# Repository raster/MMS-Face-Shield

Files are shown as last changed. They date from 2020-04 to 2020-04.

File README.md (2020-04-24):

# MMS Face Shield

This is a face shield being produced by [Milwaukee Makerspace](https://milwaukeemakerspace.org/) in Milwaukee, Wisconsin, USA.

Our design is based on v3 of the 3DVerkstan design, North American 6 hole version:

 * https://3dverkstan.se/protective-visor/protective-visor-versions/
 * https://www.youmagine.com/designs/protective-visor-by-3dverkstan/
 * https://github.com/Cederb/Faceshield.nu/

We have modified the frame to be cut from 1/4" HDPE on a CNC router. HDPE (High-density Polyethylene) is often used for cutting boards and high-touch surfaces.

_(Note: As of 2020-04-20 we have switched to using injection molding. More info below.)_

The shield will be stamped from 0.01" thick rigid clear vinyl. (We originally planned to cut with a drag knife on our CNC machine but we have found local companies that have offered to create a die and stamp them for us.)

Because of our material choices it will be easy to clean & sanitize these face shields. We're also facing a shortage of PETG sheets, so using clear vinyl that was available to us was a good option.

## Frame (CNC)

The frame is cut from 1/4" HDPE sheets on a CNC router using a 1/8" single flute spiral upcut endmill. (Note: HDPE cannot be cut on a laser cutter, but it is a great material for milling.)

## Frame (Injection Molded)

We have added the STEP file (Frame-Injection-Molding-v7.step) as we have moved to an injection molded version of the frame. This version may help if you are looking at doing injection molding. We are using HDPE plastic for our injection molded frames. We can easily produce 2000+ frames per day and the mold should be able to produce 200,000 frames during its lifetime.

We've also included an STL file (Frame-Injection-Molding-v7.stl) _for reference only!_ We make no guarantees as to the accuracy of the STL file for use beyond anything more than as a test print.

## Shield

The shield files are 8 1/2" x 11". If you can source letter size plastic you can find a variety of options for adding the holes. (The rounded corners at the bottom are not required, but are nice to have as they help prevent snagging the corner of the shield on something.)

## Cleaning

Please see the included PDF file with instructions for cleaning this reusable face shield.

## More Info

Check out our blog posts about the process and the progress: https://milwaukeemakerspace.org/tag/mmsppe/

If you want to help support our efforts, you can donate: https://charity.gofundme.com/o/en/campaign/ppe-for-milwaukee

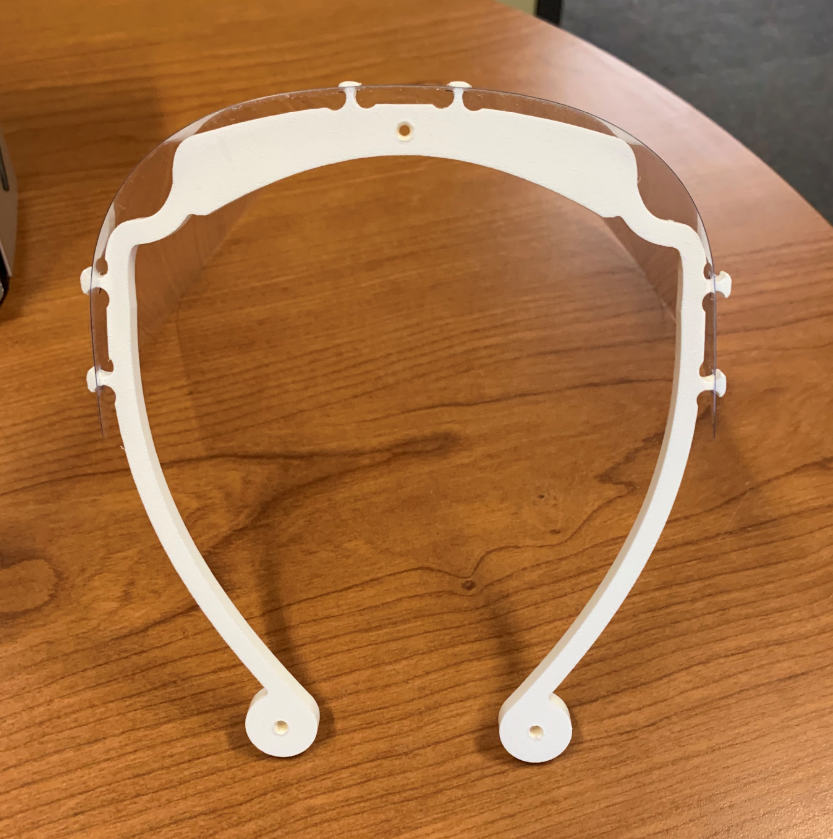
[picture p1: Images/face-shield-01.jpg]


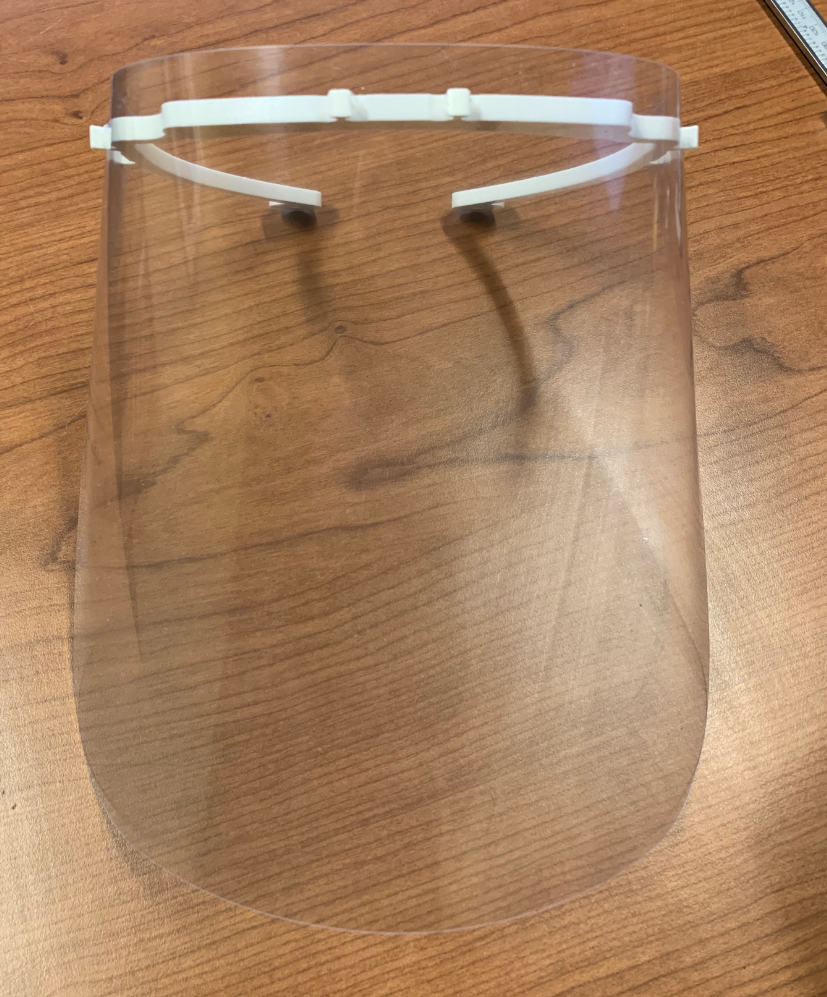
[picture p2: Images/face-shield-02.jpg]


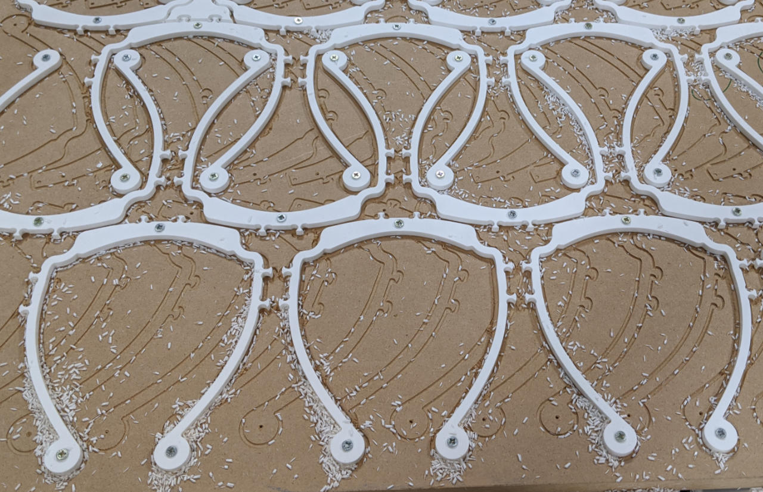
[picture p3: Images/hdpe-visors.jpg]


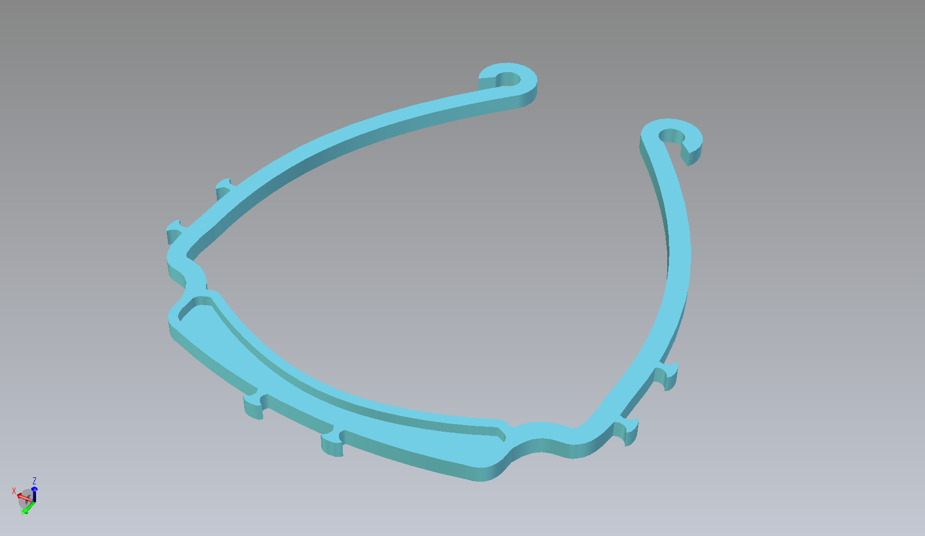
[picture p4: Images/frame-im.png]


---

Milwaukee Makerspace

https://milwaukeemakerspace.org/

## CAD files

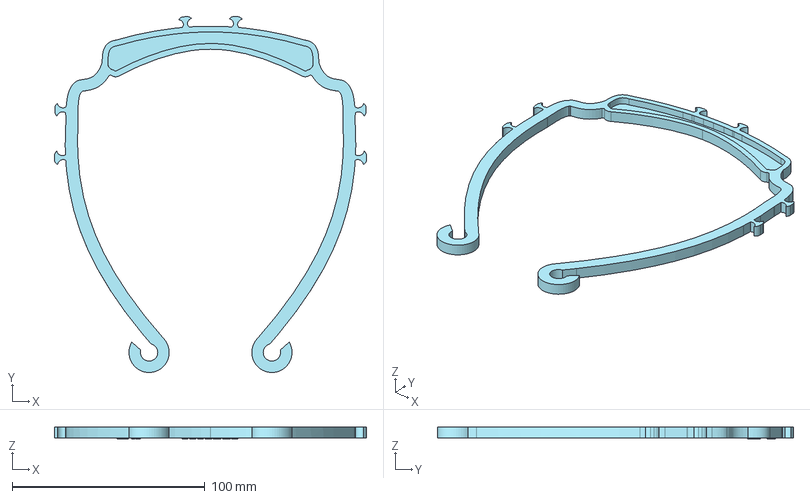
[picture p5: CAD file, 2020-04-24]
Frame/Frame-Injection-Molding-v7.step
162.1 x 184.8 x 6.09 mm

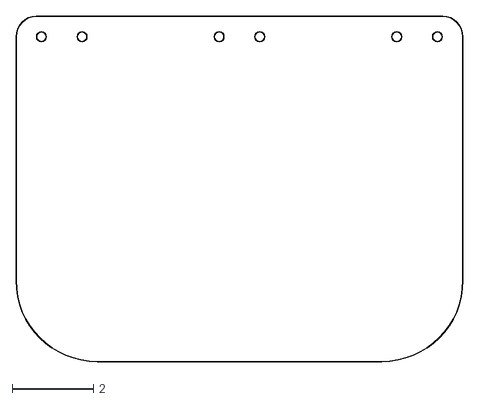
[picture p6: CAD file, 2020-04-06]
Shield/Shield-v7.dxf
11.0 x 8.50

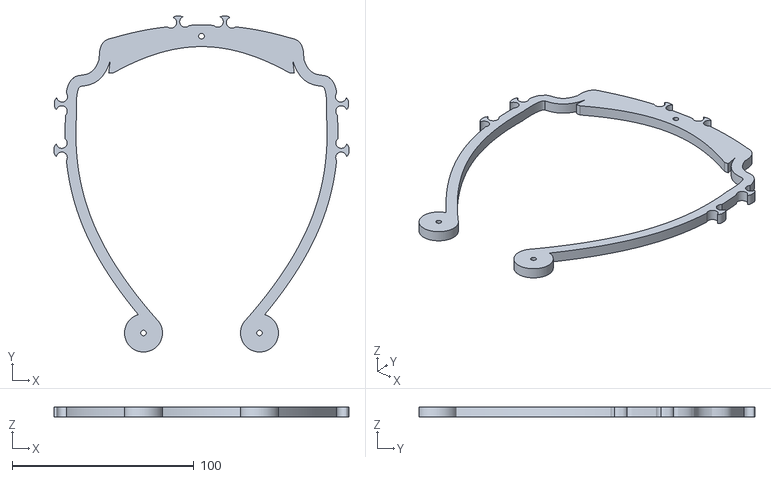
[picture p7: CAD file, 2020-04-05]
Frame/Frame-v7.stl
162.1 x 184.7 x 5.60

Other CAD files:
Frame/Frame-Injection-Molding-v7.stl
Frame/Frame-v7.dxf

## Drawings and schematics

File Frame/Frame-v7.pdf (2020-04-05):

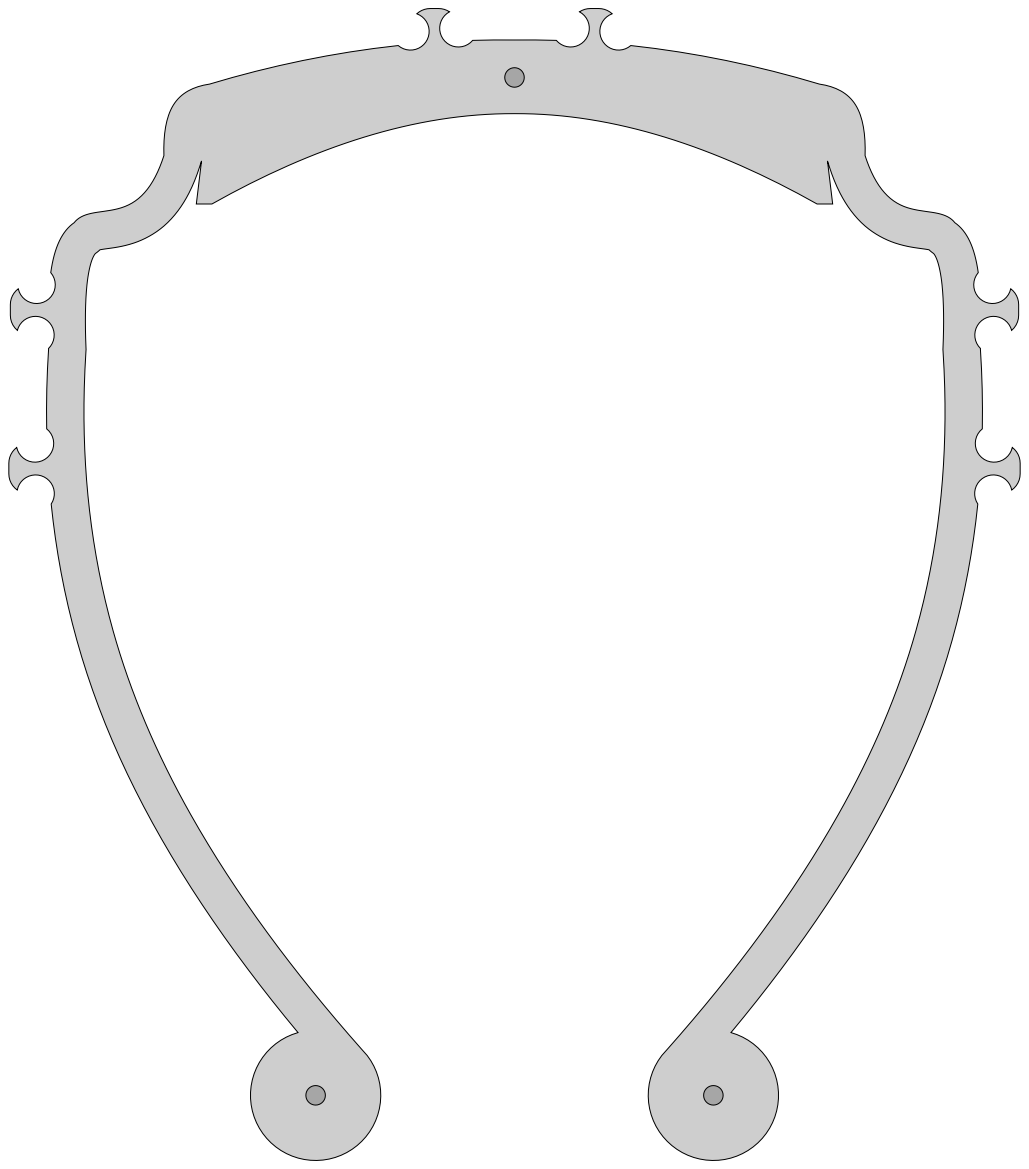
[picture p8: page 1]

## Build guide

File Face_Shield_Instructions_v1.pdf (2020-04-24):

### Milwaukee Makerspace

# Reusable Face Shield

We make this out of washable Vinyl and HDPE so that it can be cleaned and re-used.
We are 100% community funded. $10 helps us donate 15 shields to people who need them. If you love this, please share your appreciation and a photo on social media with #MMSPPE. Please do wash and re-use it wherever possible (instructions below).
Please do not share your shield with others. Thank you.
DO USE any of the following cleaners:
- Warm Soapy Water
- Hydrogen Peroxide
- Bleach water (0.5% mixture often made with 9 parts water and 1 part 5% bleach)
- Alcohol (drug or liquor store varieties are fine so long as it’s clear and at least 50% alcohol or 100 proof)
DO NOT USE excessive heat:
Sorry, no autoclave. Even a hair dryer may be too hot for the visor.
Suggested cleaning technique:
- Wipe down between patients.
- Wash at end of shift, then let air dry.
TIP: Do not wear your shield while it is still wet with sanitizer.
ASSEMBLY:
There are 6 holes along the top edge of the clear visor and 6 tabs along the outside edge of the U-shaped frame.
Slip the tabs through the holes by
1. Hooking one side of the hole over the tab
2. Push the other side down into place by pinching it down against the frame like so:
Now… A word from our community:
Our design is based on v3 of the 3DVerkstan 6 hole design (North American version) and released under a Creative Commons BY-SA License. For project info visit: milwaukeemakerspace.org/covid-19/
Design, Fabrication and Production made possible by:
ABC Woodworking LLC | fb.com/abcwoodworkingwi
Compumold Tool & Design | compumold.com
Kapco Metal Stamping, Inc | kapcoinc.com
Milwaukee Makerspace | milwaukeemakerspace.org
MRH Products | qikvin.com
Netzer Plastics | netzerplastics.com
Tools Incorporated | toolsinc.com
Redefined & Co | redefinedandco.com

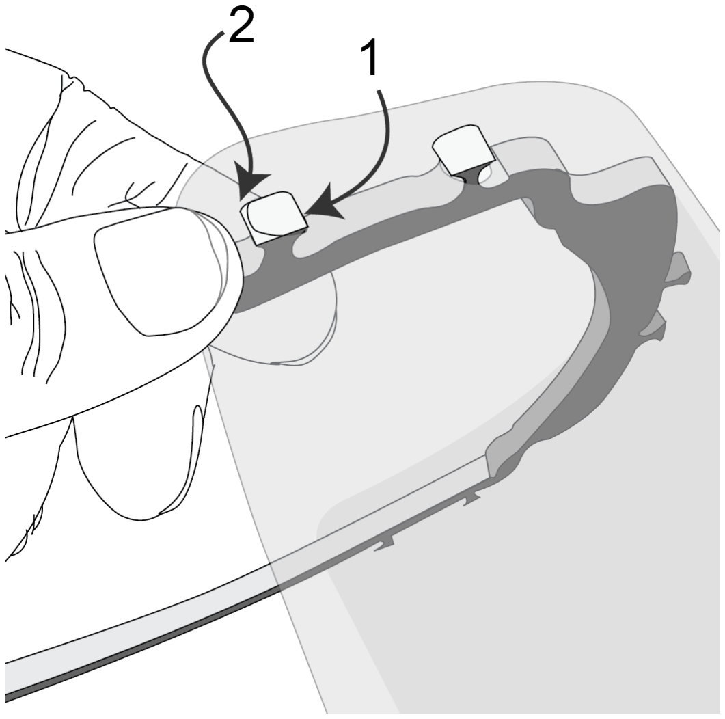
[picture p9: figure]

“We’ve got your back. This is for your face.” -Jacqueline L

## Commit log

2020-04-05 Files Released
    This is the first release of the files, please review.
    [Frame-v7.dxf, Frame-v7.stl, Shield-v7.dxf]
2020-04-06 Updated
    Removed center symmetry line
    [Shield-v7.dxf]
2020-04-07 IMPORTANT:
    Make sure printed side faces *away* from the surface of the visor or the toner is apt to transfer from the paper to the visor.
2020-04-09 V1 D5
    Please place printed side away from vinyl visor.
2020-04-24 Added injection molding details
    [Frame-Injection-Molding-v7.step]
2020-04-24 Added a reference STL file
    [Frame-Injection-Molding-v7.stl]
